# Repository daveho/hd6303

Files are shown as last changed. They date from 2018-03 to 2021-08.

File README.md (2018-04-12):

# HD6303 microcomputer project

This is a project to build a small computer using the Hitachi HD6303RP microprocessor.

## About the HD6303RP

It's an 8 bit CPU that supports an extended version of the Motorola 6800 instruction set.

Because it has some built-in peripherals (timer, UART) and 128 bytes of internal RAM, it could be considered a microcontroller.  However, it has no internal program memory, and code must be run from an external ROM.

Daniel Tufvesson's [MC3 project](http://www.waveguide.se/?article=mc3-a-diy-8-bit-computer) was extremely useful as a reference for the HD6303 and how to interface with it.  The [HD6303 datasheet](http://www.cryptomuseum.com/crypto/philips/px1000/files/hd6303rp.pdf) was also very useful.

# Circuits

So far, two circuits have been built and tested:

* [Minimal circuit](minimal.md)
* [Improved circuit](improved.md)

There is a PCB for the improved circuit:

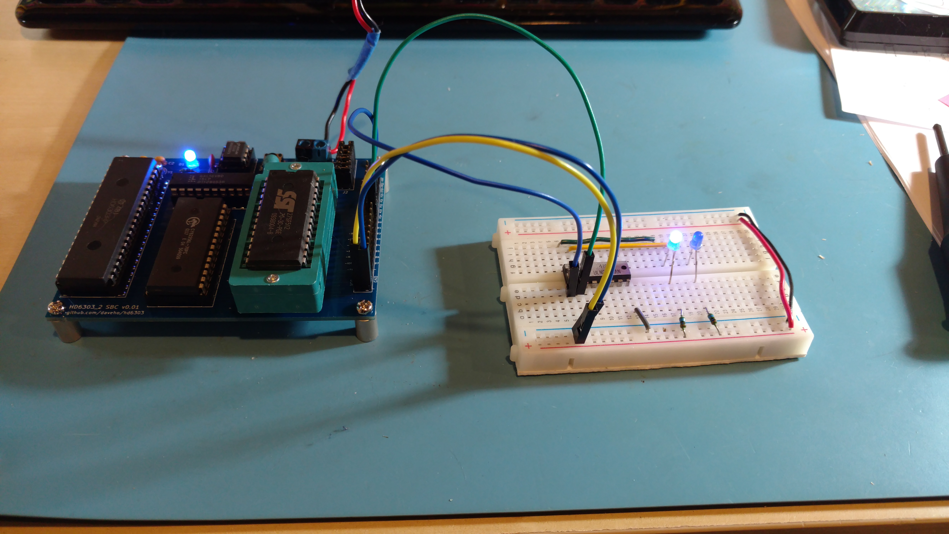
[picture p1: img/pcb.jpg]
PCB image


The data bus, lowest 10 address lines, I/O pins, and other useful signals are available on a 40 pin header, allowing the circuit to be interfaced with other peripherals.

# Future plans

I'm planning to get the UART working, and then writing some kind of monitor program.  I also plan to experiment with interfacing with some external devices.

# More info

Contact <david.hovemeyer@gmail.com>.

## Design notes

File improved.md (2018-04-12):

# HD6303 improved circuit

The improved circuit has a 32K static RAM (62256 or similar) and a 64K flash ROM (SST27SF), only 28K of which is used.

Improved circuit

The test program [blink2.asm](fw/blink2.asm) blinks LEDs connected to P23 and P24 (same as the minimal circuit.)  Note that the ULN2003A transistor array isn't shown in the schematic, but it's connected the same way as in the minimal circuit.  Build the test program using the command

```
make blink2.bin
```

and burn the resulting image into a 27C512 EPROM, SST27SF512 flash ROM, or similar.

The memory map is

```
$0000-$7FFF   static RAM (except low 256 bytes shadowed by internal registers/RAM)
$8000-$8FFF   4K area for external I/O devices
$9000-$FFFF   flash ROM
```

Glue logic is implemented using a GAL16V8.  [Galasm](https://github.com/daveho/galasm) is needed to compile the logic equations (in [glue.pld](pld/glue.pld)).  The TL866 can program both the GAL and the flash ROM.

The KiCAD project is in the `hw2` directory.  The PCB design has been fabbed and does work.

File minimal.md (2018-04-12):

# HD6303 minimal circuit

The minimal circuit has a single 27C64 EPROM, and controls two LEDs using pins P23 and P24.  The KiCAD project is in the `hw_min` directory.

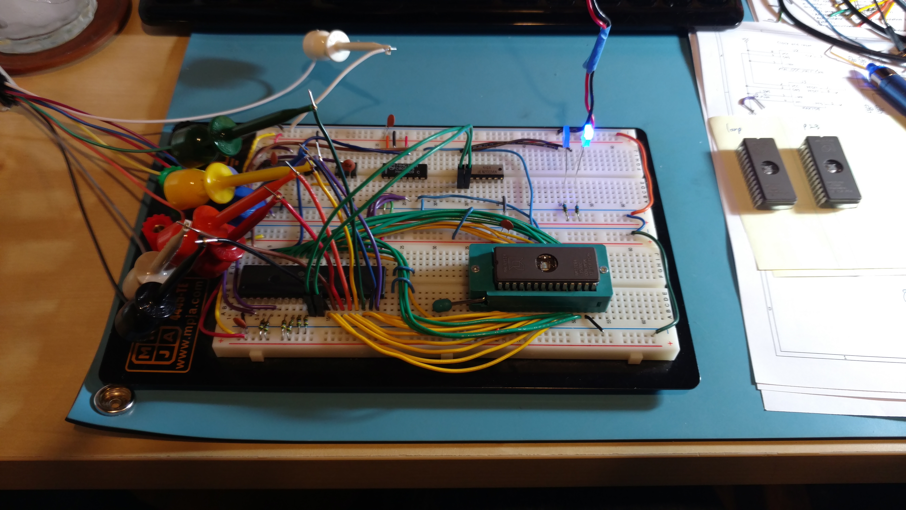
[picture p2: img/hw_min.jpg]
Minimal circuit


The test program [blink\_min.asm](fw/blink_min.asm) blinks the LEDs.  Build it using the command

```bash
make blink_min.bin
```

You'll need [dasm](http://dasm-dillon.sourceforge.net/).  The resulting image, `blink_min.bin`, can be burned into an 27C64 EPROM.  I use the Minipro TL866CS, which works very nicely under Linux using Wine.

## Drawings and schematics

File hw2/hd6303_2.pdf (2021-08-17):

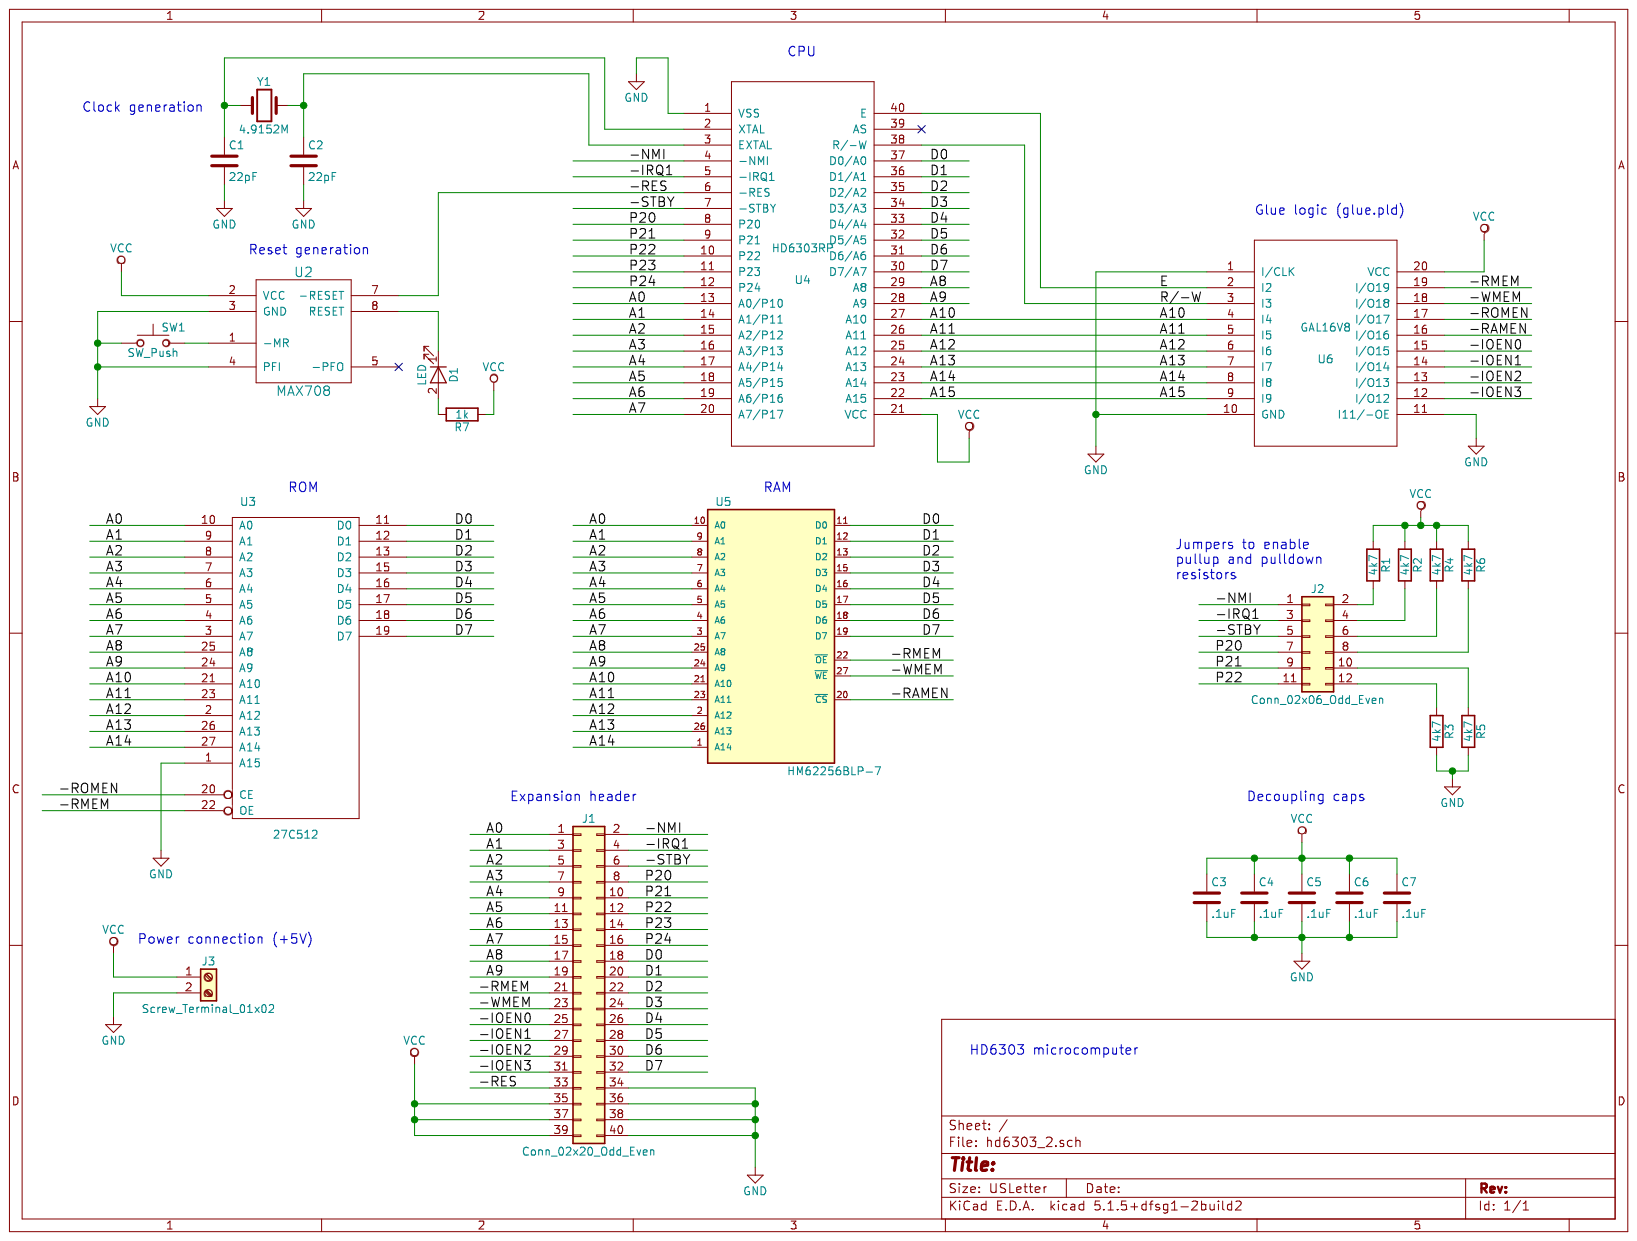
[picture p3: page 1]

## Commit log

2018-02-27 basic circuit is in place
    If I do say so myself, I found a pretty clever way to
    implement a nice memory map for ROM, RAM, and I/O,
    using only '02, '32, and '138 chips, with no unused
    gates.
    [hd6363.sch]
2018-02-28 added an output port
    [hd6363.sch]
2018-03-01 use letter size paper, add document title
    [hd6363.sch]
2018-03-01 some schematic editor properties
2018-03-01 correct part number of filenames
    [hd6303.kicad_pcb, hd6303.sch]
2018-03-01 add pull-ups for -NMI, -IRQ1, -STBY
    [hd6303.sch]
2018-03-02 blinking LED demo
2018-03-03 rearranged, better control for output port
    [hd6303.sch]
2018-03-03 minimal test circuit and test program
    The full circuit didn't work, and from looking
    at logic analyzer traces of the data bus, it sort
    of looked like the HD6303 was running in multiplexed
    mode rather than non-multiplexed mode. The minimal
    circuit should be more or less the least complicated
    circuit that can run useful code.
    [hs6303_min.kicad_pcb, hs6303_min.sch]
2018-03-04 successfully lights a LED on P23/P24!
    Once I can get a delay loop working, we should
    be able to blink the LEDs.
2018-03-04 blinking LEDs is working!
    Rate is too fast: need to improve the delay loop.
2018-03-04 experiment to use GAL16V8 for glue logic
2018-03-04 second version of circuit
    Uses GAL16V8 for glue logic: tests good on
    breadboard, and does the work of 4 logic chips
    in the original circuit, as well as implementing
    a better memory map (with 32K of RAM excluding
    the HD6303's internal registers and RAM, 28K of
    ROM, and 4K of I/O space divided into 1K chunks.)
    [hd6303_2.kicad_pcb, hd6303_2.sch]
2018-03-17 use passive crystal and internal clock gen
    [hd6303_2.sch]
2018-03-17 loop demo for new (hw2) circuit
    Verified working on the breadboard (I think!)
2018-03-17 blinking LED demo for new (hw2) circuit
2018-03-17 prepare for PCB
    Added expansion header for interfacing with external
    devices (which will eventually become part of the
    main schematic.)
    Added jumpers to allow pullups and pulldowns to be
    connected selectively.
    [hd6303_2.sch]
2018-03-17 added screw terminal for power connection
    [hd6303_2.sch]
2018-03-17 choose footprints, generate netlist
    [hd6303_2.sch]
2018-03-18 connect -RES on the expansion header
    The circuit which uses the 4053 analog mux to
    allow access to P20..P22 post-reset needs access
    to the reset signal.
    [hd6303_2.sch]
2018-03-18 started PCB layout
    Component footprints look reasonable. The reset
    button looks to be a standard 6mm tactile switch.
    [hd6303_2.kicad_pcb]
2018-03-18 use smaller footprint for resistors
    [hd6303_2.kicad_pcb, hd6303_2.sch]
2018-03-18 reasonable component placement?
    [hd6303_2.kicad_pcb]
2018-03-18 apply OSHPark design rules
    [hd6303_2.kicad_pcb]
2018-03-18 started routing some traces
    [hd6303_2.kicad_pcb]
2018-03-18 continuing to route traces
    [hd6303_2.kicad_pcb]
2018-03-18 more traces...
    [hd6303_2.kicad_pcb]
2018-03-18 more traces, getting there...
    [hd6303_2.kicad_pcb]
2018-03-18 more traces routed...
    [hd6303_2.kicad_pcb]
2018-03-18 still making progress...
    [hd6303_2.kicad_pcb]
2018-03-18 all traces on expansion header routed
    [hd6303_2.kicad_pcb]
2018-03-18 some tidying up
    [hd6303_2.kicad_pcb]
2018-03-18 all traces routed!
    [hd6303_2.kicad_pcb]
2018-03-19 board outline, silkscreen tweaks
    [hd6303_2.kicad_pcb]
2018-03-19 reroute a couple of traces, silkscreen additions
    [hd6303_2.kicad_pcb]
2018-03-19 label expansion header pins
    [hd6303_2.kicad_pcb]
2018-03-19 make title/URL smaller
    Otherwise they will be obscured by the ZIF socket.
    [hd6303_2.kicad_pcb]
2018-03-19 generated gerbers for Seeed Studio
    [hd6303_2.kicad_pcb]
2018-03-19 script to rename gerber files
2018-03-19 ignore gerber directory
2018-03-19 remove old circuit
    Wasn't able to get it working successfully on the breadboard,
    and the new (hw2) circuit has a better memory map.
    [hd6303.kicad_pcb, hd6303.sch]
2018-03-19 picture and more info for improved circuit
2018-03-21 working on interface circuit for AY-3-8913
    [ay8913.kicad_pcb, ay8913.sch]
2018-03-22 more work on AY-3-8913 circuit
    [ay8913.sch]
2018-03-22 use -RST signal
    [ay8913.sch]
2018-03-22 update to schematic editor props
2018-03-22 use GAL16V8 to divide the 4MHz to 2MHz
    This works fine and eliminates the need for the 74HC74.
    [ay8913.sch]
2018-04-12 picture of PCB
2021-08-17 added schematic PDF
    also committed some files from symbol rescue (I don't
    really understand KiCad library management)
